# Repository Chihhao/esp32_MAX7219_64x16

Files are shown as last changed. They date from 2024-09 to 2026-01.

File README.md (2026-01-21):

# 💡 ESP32 MAX7219 LED Matrix Display

這是一個基於 ESP32 的 LED 點矩陣顯示專案，整合了 WiFi 網頁設定、RTC 時間顯示、以及條碼掃描器輸入功能，適合用於創客空間或資訊看板。  
本專案提供兩種顯示規格的程式碼：
1.  **64x16 (寬版)**: 使用 16 個 MAX7219 模組 (雙排)。
2.  **64x8 (窄版)**: 使用 8 個 MAX7219 模組 (單排)。

## 📸 專案展示 (Gallery)

### 寬版 (64x16)
Big Demo
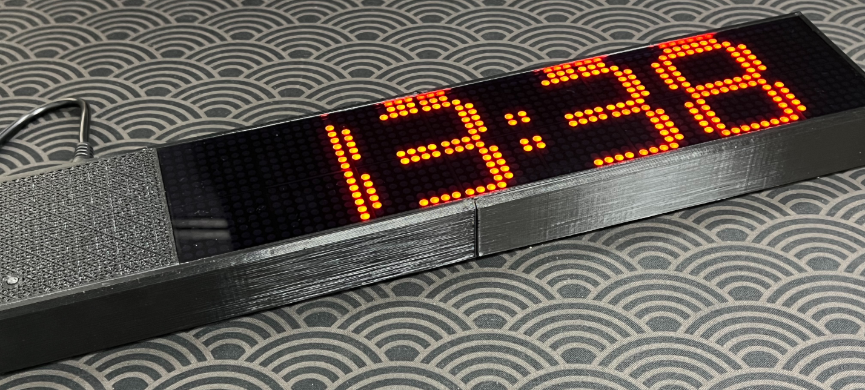
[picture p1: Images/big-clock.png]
Big Clock

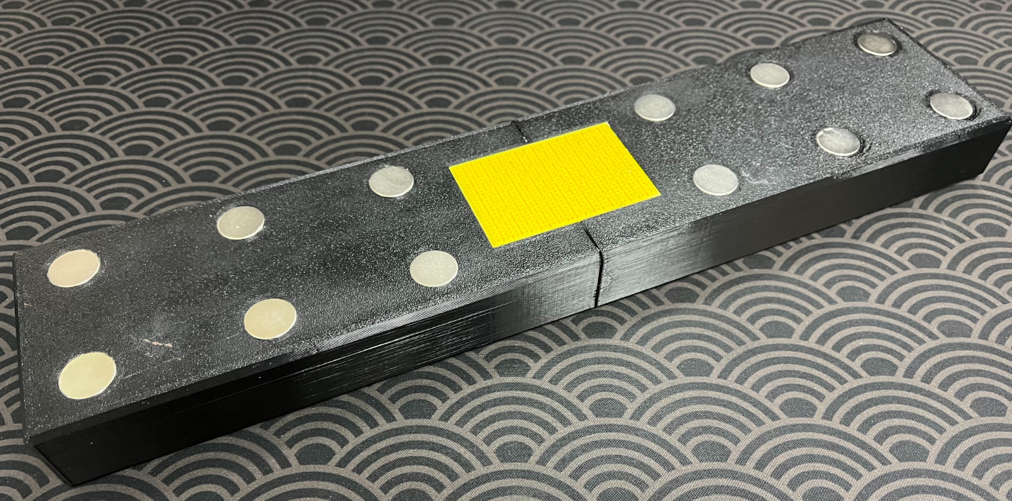
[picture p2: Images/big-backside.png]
Big Backside

Big Inside

### 窄版 (64x8)
Big Demo
Barcode Reader

---

## ✨ 功能特色 (Features)

*   **📶 WiFi AP 設定介面**:
    *   ESP32 啟動後建立獨立熱點 (AP)，方便手機或電腦連線設定。
    *   提供網頁介面修改三組輪播訊息及同步系統時間。
    *   設定內容儲存於 EEPROM，斷電後資料不遺失。
*   **ℹ️ 資訊顯示**:
    *   **輪播訊息**: 支援三組自訂文字訊息 (僅支援英文)，具備滾動與進場動畫效果。
    *   **時間顯示**: 內建 RTC 模組，可顯示大字體時間 (時:分) 與完整日期資訊。
    *   **雙區顯示**:
        *   **64x16**: 分為上下兩區 (Zone Upper / Zone Lower)。
        *   **64x8**: 分為左右兩區 (Zone Left / Zone Right)。
*   **🔫 條碼掃描互動**:
    *   支援 PS2 介面的條碼掃描器。
    *   掃描條碼後，螢幕會暫停輪播，立即顯示掃描到的內容 (停留 30 秒)。
*   **🌱 節能排程**:
    *   內建工作時間判斷，僅在 **08:30 ~ 17:30** 開啟顯示，其餘時間自動關閉以節省電力。

## 📦 版本說明 (Versions)

### 1. 64x16 寬版 (主要版本)
*   **程式碼路徑**: `esp32_MAX7219_64x16/`
*   **硬體配置**: 16 個 MAX7219 模組，排列為 64行 x 16列。
*   **顯示邏輯**: 上下兩行同步顯示或顯示不同資訊。

### 2. 64x8 窄版
*   **程式碼路徑**: `esp32_MAX7219_64x8/`
*   **硬體配置**: 8 個 MAX7219 模組，排列為 64行 x 8列 (單排)。
*   **顯示邏輯**:
    *   **左側 (Zone Left)**: 固定顯示時間 (時:分)。
    *   **右側 (Zone Right)**: 輪播文字訊息。

## 🛠️ 硬體與製作 (Hardware & Build)

### 📝 材料清單 (BOM)
1.  **微控制器**: NodeMCU-32S (ESP32)
2.  **顯示模組**: MAX7219 Dot Matrix Module (FC-16 形式)
    *   64x16 版本需 16 片 (或 4 組 4合1 模組串接)
    *   64x8 版本需 8 片
3.  **RTC 時鐘模組**: DS3231
4.  **輸入裝置**: PS2 介面條碼掃描器 (或 PS2 鍵盤) + PS/2 母座
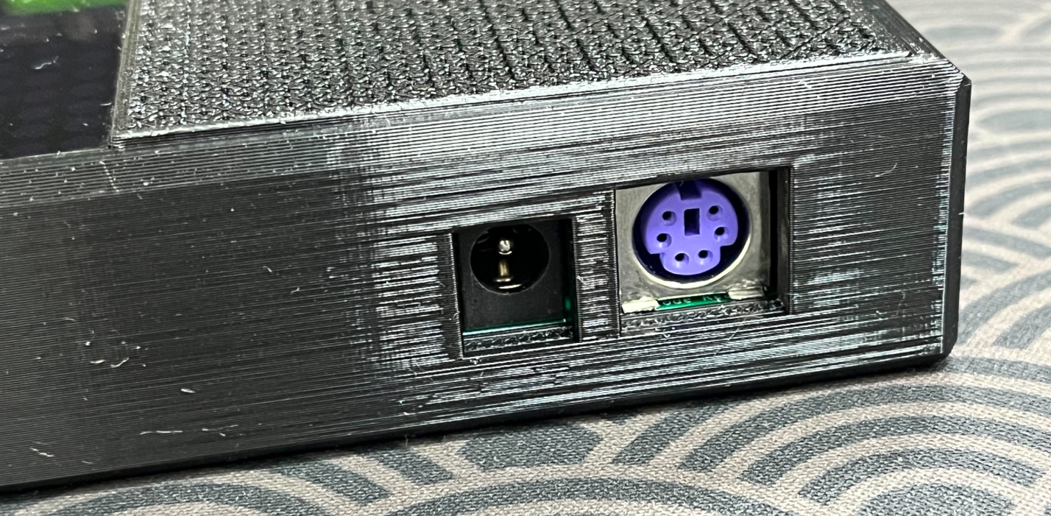
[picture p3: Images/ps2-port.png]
PS2 Port
    
5.  **電源供應**:
    *   **64x16 版本**: 建議使用 **5V 4A** (至少 3A)，以確保全亮時系統穩定。
    *   **64x8 版本**: 建議使用 **5V 2A**。
6.  **其他**:
    *   Reset Button
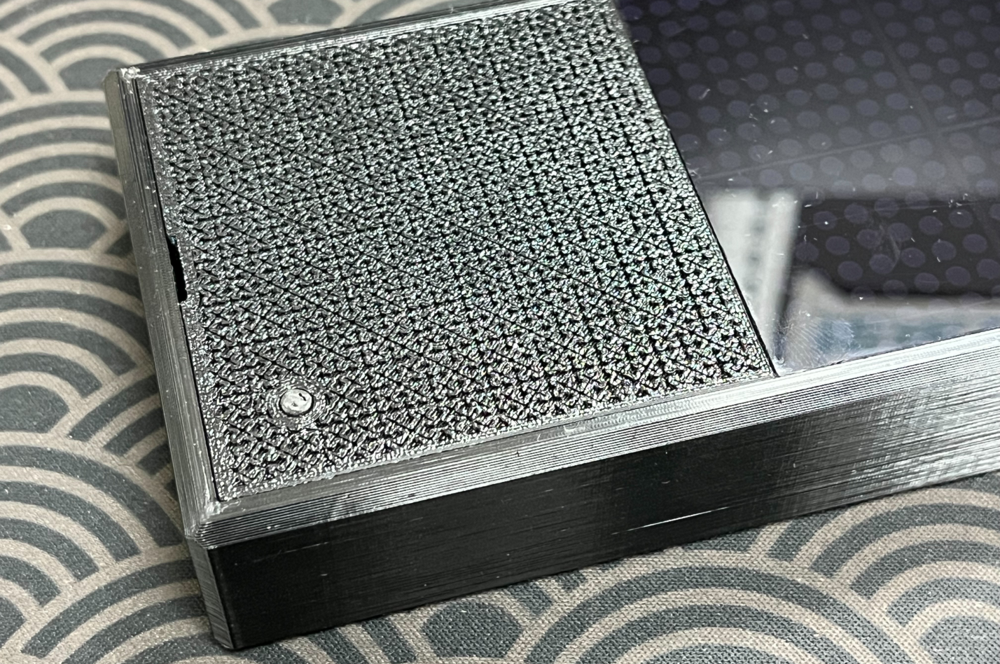
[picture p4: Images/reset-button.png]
Reset Button
        
    *   PCB (可參考下方 Gerber 檔)
    *   3D 列印外殼
    *   強力磁鐵 (直徑 18.2mm / 厚 2mm)
    *   深色透明壓克力 (雷射切割)

### 🔌 接線說明 (Pinout)

| 模組 | 接腳名稱 | ESP32 GPIO | 備註 |
| :--- | :--- | :--- | :--- |
| **MAX7219** | CLK | 18 | SPI Clock |
| | DATA (DIN) | 23 | SPI MOSI |
| | CS | 5 | Chip Select |
| **PS2 Scanner** | Data | 36 | Input Only |
| | Clock | 39 | Input Only |
| **DS3231** | SDA | 21 | I2C SDA (Default) |
| | SCL | 22 | I2C SCL (Default) |

### 原理圖 (Schematic)
Schematic

### PCB 設計
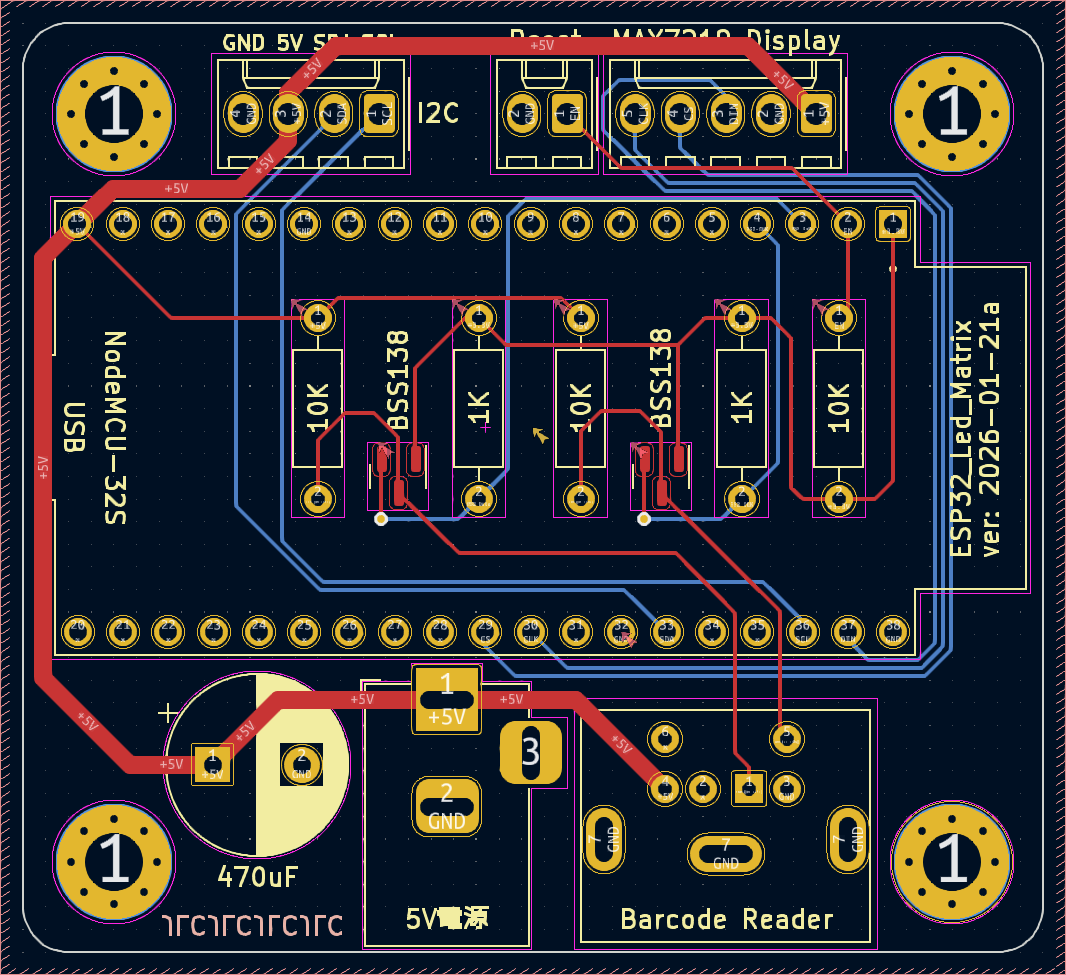
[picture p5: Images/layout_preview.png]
Layout Preview

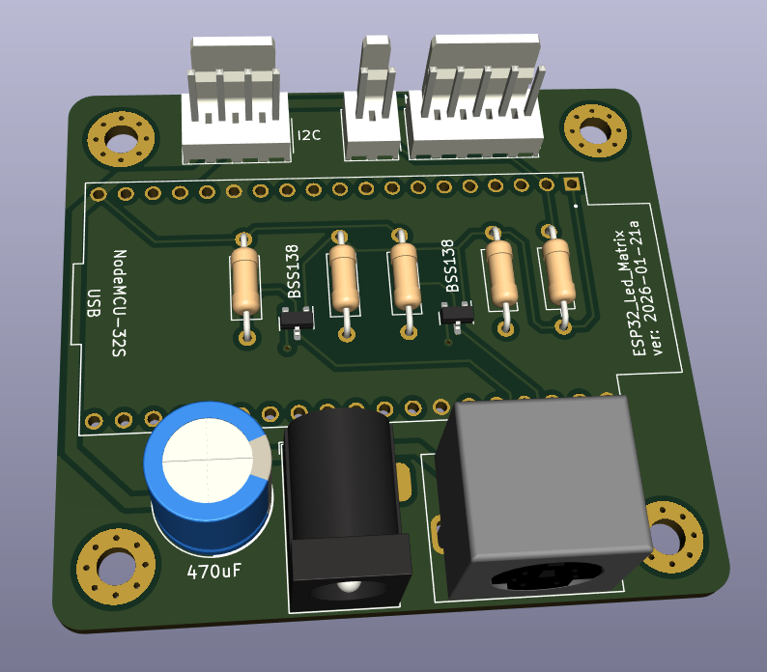
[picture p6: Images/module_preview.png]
Module Preview


### 3D 外殼模型
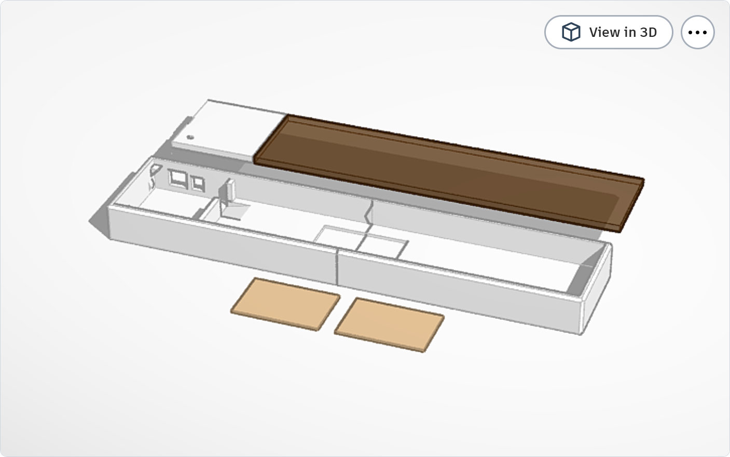
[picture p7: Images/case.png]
Case

* 寬版(64x16) Tinkercad Model: https://www.tinkercad.com/things/0vOz0woKdCv-
* 窄版(64x8) Tinkercad Model: https://www.tinkercad.com/things/j6S2HNCI5wD-

## 軟體設定 (Software Setup)

### 函式庫依賴
請在 Arduino IDE 中安裝以下函式庫：  
*註：版本號為開發時使用的版本，建議使用最新版，若有問題可嘗試回退。*  
1.  Arduino IDE :  1.8.19  
2.  ESP32 Board Library : 3.0.4  
3.  `MD_Parola` by MajicDesigns (v3.7.3)
4.  `MD_MAX72xx` by MajicDesigns (v3.5.1)
5.  `Bonezegei_DS3231` (v1.0.2)
6.  `PS2Keyboard` (v2.4)
7.  `Time` (TimeLib) (v1.6.1)

## 🚀 使用說明 (Usage)

1.  **⚡ 啟動**: 送電後，顯示器會顯示初始訊息或時間。
2.  **🔗 連線設定**:
    *   搜尋 WiFi SSID: `ESP32_LedDisplay` (64x16) 或 `LedDisplay_Nory` (64x8)
    *   密碼: `ESP32_LedDisplay` (64x16) 或 `LedDisplay_Nory` (64x8)
    *   *註：SSID 與密碼定義於程式碼開頭，可自行修改。*
3.  **🌐 網頁控制**:
    *   開啟瀏覽器，輸入網址 `http://192.168.4.1`
    *   **Text Setting**: 輸入 Message 1~3，點擊 "Send Text" 更新顯示。
    *   **Reset Time**: 點擊可將 ESP32 時間同步為目前瀏覽器裝置的時間。
4.  **🔢 條碼輸入**:
    *   直接使用連接的掃描器掃描條碼，螢幕將顯示 "Input: [條碼內容]"。

## ⚠️ 注意事項
*   **工作時間**: 若在 08:30 前或 17:30 後測試，螢幕將保持關閉。可修改程式碼中的 `isWorkTime()` 函式調整時段。
*   **PS2 接腳**: GPIO 36/39 為僅輸入 (Input Only) 接腳，適用於單向傳輸的掃描器。

---

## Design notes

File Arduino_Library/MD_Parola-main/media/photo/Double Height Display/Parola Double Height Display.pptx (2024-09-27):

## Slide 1

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
Rotate 90°

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
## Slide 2

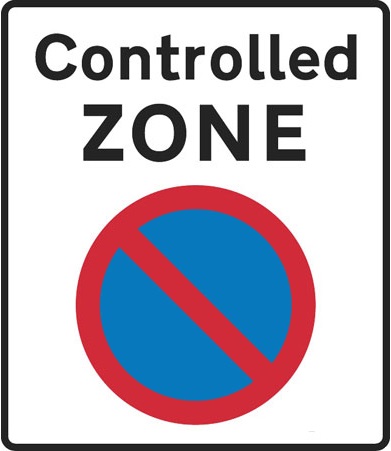
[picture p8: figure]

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
Zone 2

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
Zone 1

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
Zone 0

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
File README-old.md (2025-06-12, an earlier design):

# ESP32 跑馬燈  

## 功能  
1. 跑馬燈，三條訊息輪播 (僅支援英文)  
2. 顯示時間  
3. 顯示條碼機輸入 (最多20碼)  
4. 透過 wifi 設定跑馬燈的訊息與時間  
    (1) 連接 SSID: ESP32_LedDisplay，密碼: 1234567890  
    (2) 瀏覽 http://192.168.4.1  

### 寬版(64*16)
  
  
  
  
  
  

### 窄版(64*8)


## 材料
(1) NodeMCU-32S  
(2) MAX7219 LED點矩陣顯示模組 (64x16)  
(3) DS3231 RTC模組  
(4) Reset Button  
(5) PS/2 母座  
(6) PCB (JLCPCB)  
(7) 3D 列印外殼 ([抗靜電PLA](https://mastech3d.shopstore.tw/item/MPLAE5?srsltid=AfmBOordnhgKTl34iQG4GHte7n62okU-jecyvpEcQZp8lnUj-52Lklmb))  
(8) 強力磁鐵 (直徑 18.2mm / 厚 2mm)  
(9) 深色透明壓克力 (雷射切割)  

## Arduino Library Version  
(1) IDE: Arduino 1.8.19  
(2) Board Library: ESP32 3.0.4  
(3) MD_MAX72XX 3.5.1  
(4) MD_Parola  3.7.3  
(5) Bonezegei_DS3231 1.0.2  
(6) PS2Keyboard 2.4  
(7) Time 1.6.1  

## 原理圖  
  

## PCB
  
  

## 3D Model  
* [寬版(64*16)] Tinkercad Model: https://www.tinkercad.com/things/0vOz0woKdCv-
* [窄版(64*8)] Tinkercad Model: https://www.tinkercad.com/things/j6S2HNCI5wD-


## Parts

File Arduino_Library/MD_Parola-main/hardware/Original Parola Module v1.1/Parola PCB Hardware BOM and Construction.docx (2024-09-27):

# Parola for Arduino Hardware - Bill of Materials and Assembly

## Bill of Materials

Qty | Part | Description
1 | PCB | Printed Circuit Board.
1 | Maxim MAX7219 IC | LED controller.
1 | LD-1088 | 8x8 3mm common anode LED matrix display.
1 | 5 pin 2.54 mm single row angled socket connector | Right angle connector (female) cut from longer length.
1 | 5 pin 2.54 mm single row angled pin connector | Right angle connector (male) cut from longer length.
2 | 8 pin DIP IC socket strip | Socket strip cut from longer length, one for each side of the LED matrix.
1 | 62k Ohm resistor | Resistor sized according to rules for Rset in the MAX7219 datasheet – refer to the datasheet for appropriate values. Something close is sufficient as long as all the resistors are the same, as this controls the LED brightness.
1 | 10µF electrolytic capacitor | Electrolytic capacitor
1 | 0.1µF ceramic capacitor | Ceramic capacitor

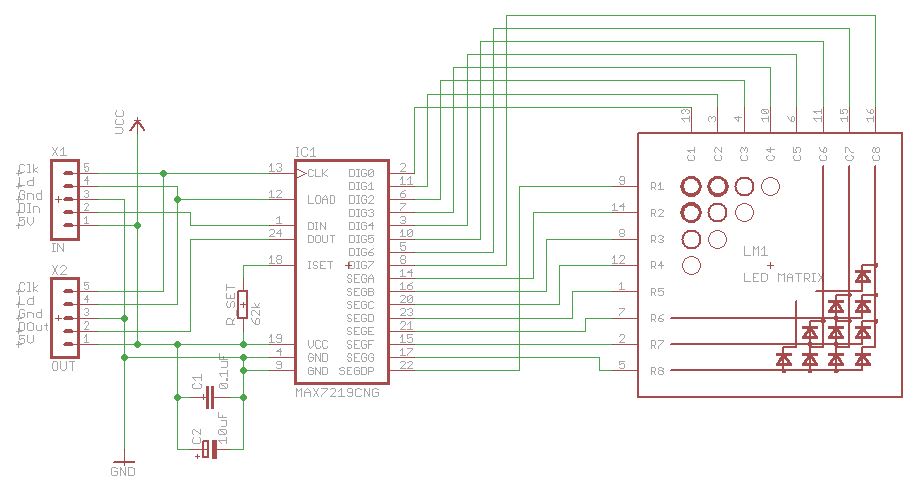
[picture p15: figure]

Figure 1 – Hardware Circuit Schematic

## Component Sources

The PCB can be manufactured at Seeed Studio (http://www.SeeedStudio.com) using the files available on the project web site. The zip file distributed contains all the data required by this service. PCB manufacturing can be found in the Services menu, and the board size is 30x50 mm.

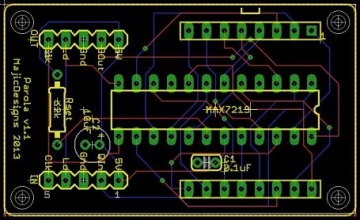
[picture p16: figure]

Figure 2 - PCB Layout

Tayda Electronics (http://www.taydaelectronics.com) is an inexpensive source for all the components

- MAX7219 ICs (Part number A-1018)
- LED Dot Matrix 8x8 Display Red 3mm Common Anode (A-1013)
- 40 Pin 2.54 mm Angle Single Row Pin Header (A-199)
- 40 Pin 2.54 mm Single Row Right Angle Female Pin Header (A-1012)
- 40 Pin DIP SIP IC Sockets Adaptor Solder Type (A-1605)
- 62k Ohm 1/4W 5% Carbon Film Resistor (A-2122)
- 10µF 50V 105C Radial Electrolytic Capacitor 5x11mm (A-4554)
- 0.10µF 50V Multilayer Ceramic Capacitor (A-214)

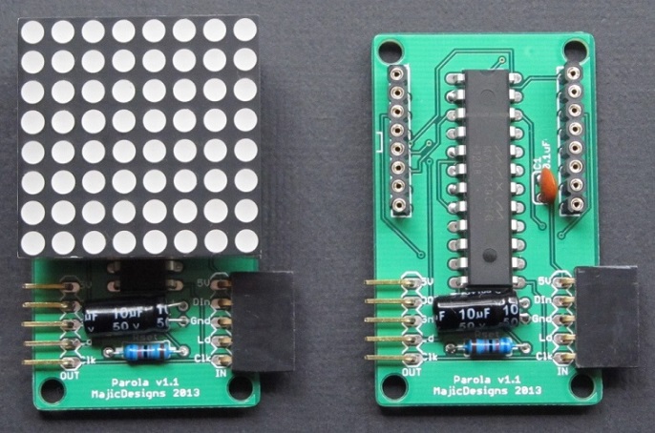
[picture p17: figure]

Figure 3 - Completed hardware

## Assembly Instructions

All items, except for the edge connectors and the LED matrix, are straightforward to assemble. The recommended order of assembly is:

i. Edge connectors
ii. Resistor
iii. Integrated Circuit – insert as per silk screen orientation, without IC socket
iv. Capacitors – note polarity on the 10µF electrolytic capacitor
v. LED matrix, with socket attached

### The Edge Connectors

This process is easiest if two modules are assembled concurrently.

1. Cut 5 pins from the female edge connector. The strip need has to be separated in the middle of the 6th connector. Use sandpaper or a file to neaten up the jagged cut end.
2. Do the same for the male connector. In this case, the separation is between pins.

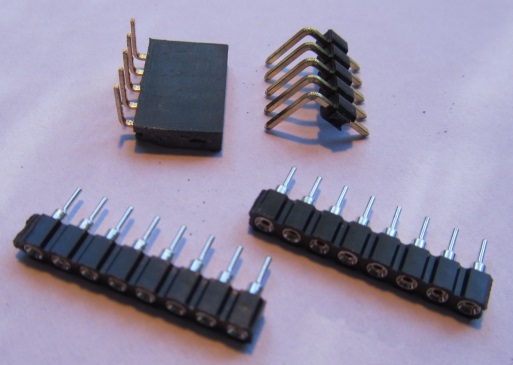
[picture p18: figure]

Figure 4 - Connectors cut to size

3. Remove the angled header pins from their plastic matrix. They should slide out relatively easily. If they don’t, use side cutters to break away the plastic material. You will be left with 5 right angle pins with one leg slightly longer than the other.

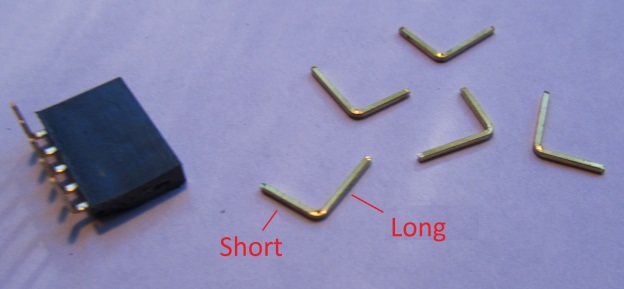
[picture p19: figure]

Figure 5 - Separated pins

4. Insert the shorter end into the socket so that the final subassembly looks like Figure 6 below.

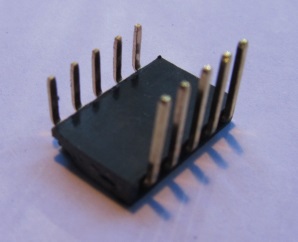
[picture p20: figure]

Figure 6 - Connector subassembly

5. Insert the connector subassembly into 2 inverted PCBs laid alongside each other, supported by the long socket strips. This ensures that the connector assembly remains flat and parallel to the PCB, as the spacers and connectors are the same thickness.

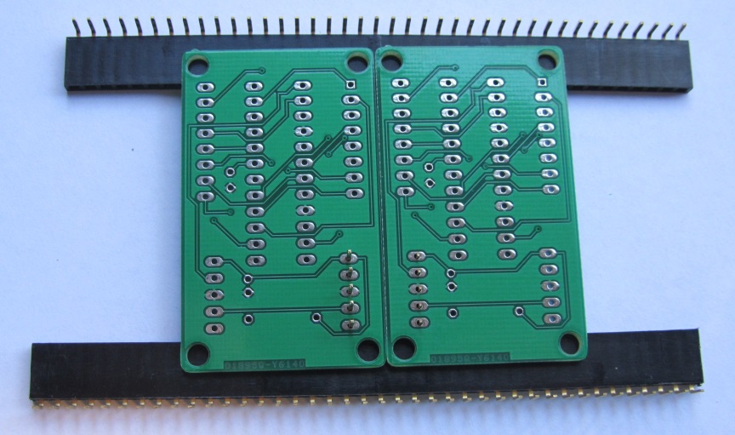
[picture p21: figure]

Figure 7 - PCB supported for connector soldering

6. Double check that the PCBs and the connectors are inserted in the same direction as modules already assembled, and that the PCB is really upside-down (no silk screen text visible).
7. Check that the two PCBS are lying parallel to each other, either touching or with a consistent small (< 1 mm) gap along the common long edge. Ensure this gap remains the same while you solder the edge connector in place.

### The LED Matrix

1. Attached the IC socket strips to the LED matrix pins. This makes it easier to insert the pins into the PCB as they remain straighter and stiffer than the ‘bare’ pins. Ensure they are fully inserted.

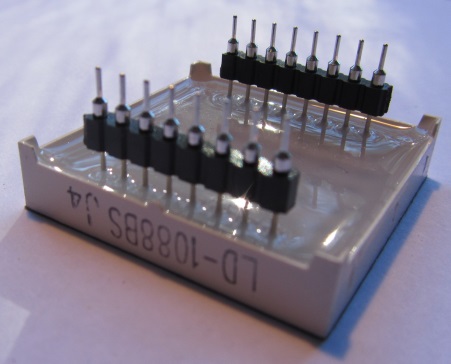
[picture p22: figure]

Figure 8 - LED matrix inserted into socket strip

2. One edge of the LED matrix has a small plastic square tab on the lower edge. This should be aligned with the square mark silkscreened near the edge of the PCB.


Figure 9 - Alignment tab and PCB silkscreen

3. Insert the LED matrix with sockets connected into the PCB.
4. Invert the PCB and press down on the back to ensure that the pins are pushed into the PCB holes as far as they will go. This ensures that the faces of all the matrices will be flush when the modules are connected side by side.
5. While keeping pressure, solder the four corner pins to lock it in place. Check that the matrix is correctly inserted before completely soldering all the remaining LED matrix pins to the PCB.

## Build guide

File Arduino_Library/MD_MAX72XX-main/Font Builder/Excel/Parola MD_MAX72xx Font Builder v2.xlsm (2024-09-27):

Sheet: Instructions
MD_MAX72xx and Parola Font Editor v2.1
Purpose
The purpose of this workbook is to simplify the coding of LED matrix font files for the MD_MAX72xx and MD_Parola libraries. All characters are 8 or 16 pixels high and can be as wide as necessary. This tool allows up to 10 columns.
Principles of Operation
The font definitions are a series of bytes representing columns of data (one column of the LED display) preceded by the number of bytes in that definition. This allows both variable size characters and fixed size characters to be defined in the same way. The ASCII code for the character is inferred from the position in the file (i.e., the 100th character definition is for ASCII value 99, as numbering starts at 0).
5, 62, 107, 79, 107, 62, // 2 - Happy Smiley
In the above example, 5 is the number of bytes in the definition and the remaining bytes are the bitmap for the character. The comment line is auto generated by this tool to include the ASCII value and the optional label entered for this character.
Workflow
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

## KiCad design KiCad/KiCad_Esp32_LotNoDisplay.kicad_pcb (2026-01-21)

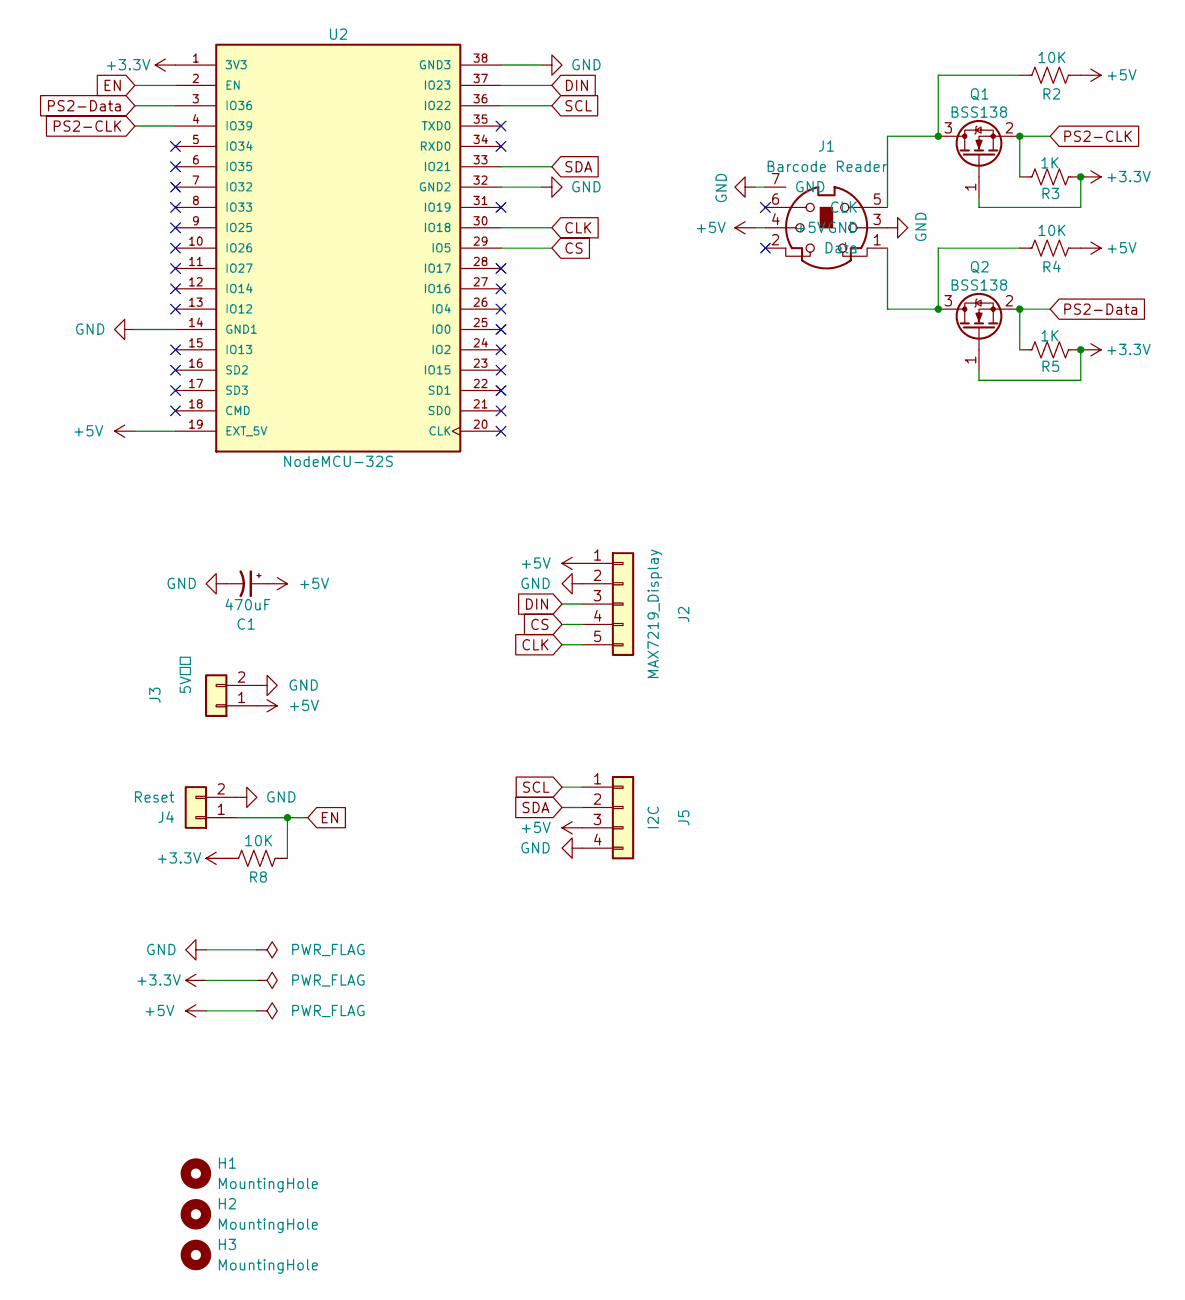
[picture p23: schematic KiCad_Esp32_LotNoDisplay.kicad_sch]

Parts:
C1: 470uF; CP_Radial_D10.0mm_P5.00mm
H1, H2, H3: MountingHole; MountingHole_3.2mm_M3_Pad_Via
J1: Barcode Reader; Connector_Mini-DIN_Female_6Pin_2rows
J2: MAX7219_Display; Molex_KK-254_AE-6410-04A_1x04_P2.54mm_Vertical
J3: 5V電源; TerminalBlock_Phoenix_MKDS-1,5-2-5.08_1x02_P5.08mm_Horizont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
J4: Reset; Molex_KK-254_AE-6410-02A_1x02_P2.54mm_Vertical
J5: I2C; Molex_KK-254_AE-6410-04A_1x04_P2.54mm_Vertical
Q1, Q2: BSS138; SOT-23
R2, R4, R8: 10K; R_0805_2012Metric_Pad1.20x1.40mm_HandSolder
R3, R5: 1K; R_0805_2012Metric_Pad1.20x1.40mm_HandSolder
U2: NodeMCU-32S; MODULE_ESP32-DEVKITC; PARTREV N/A

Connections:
+3.3V: Q1.1 (G), Q2.1 (G), R3.1, R5.1, R8.2, U2.1 (3V3)
+5V: C1.1, J1.4 (+5V), J2.1, J3.1, J5.3, R2.1, R4.1, U2.19 (EXT_5V)
CLK: J2.5, U2.30 (IO18)
CS: J2.4, U2.29 (IO5)
DIN: J2.3, U2.37 (IO23)
EN: J4.1, R8.1, U2.2 (EN)
GND: C1.2, J1.3 (GND), J1.7 (GND), J2.2, J3.2, J4.2, J5.4, U2.14 (GND1), U2.32 (GND2), U2.38 (GND3)
unnamed: J1.1 (Data), Q2.3 (D), R4.2
unnamed: J1.5 (CLK), Q1.3 (D), R2.2
PS2-CLK: Q1.2 (S), R3.2, U2.4 (IO39)
PS2-Data: Q2.2 (S), R5.2, U2.3 (IO36)
SCL: J5.1, U2.36 (IO22)
SDA: J5.2, U2.33 (IO21)

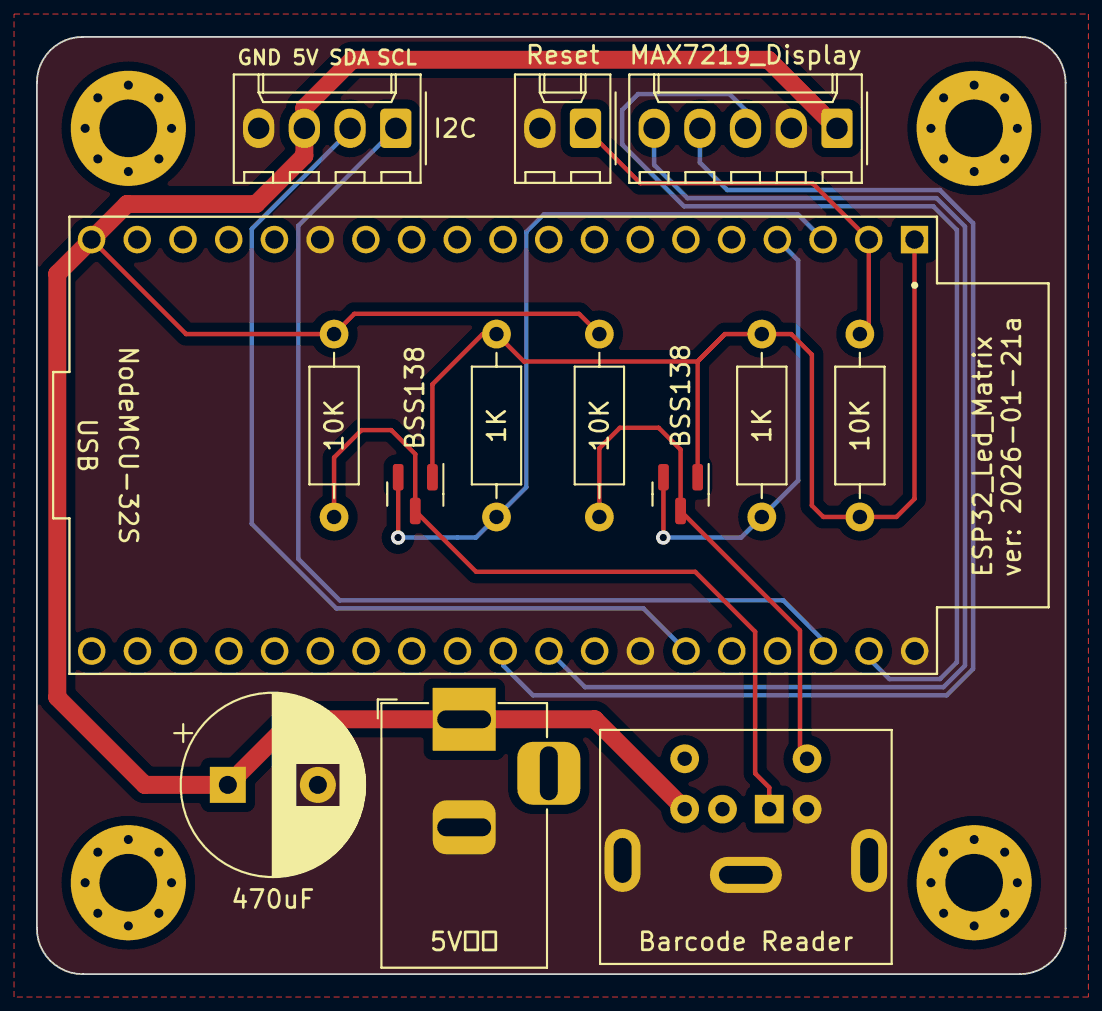
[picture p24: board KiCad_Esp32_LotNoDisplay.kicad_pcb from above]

Board: 2 copper layers, 57.1 x 52.1 mm, 18 parts (0 on the bottom side), 13 nets.

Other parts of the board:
H4: MountingHole; MountingHole_3.2mm_M3_Pad_Via

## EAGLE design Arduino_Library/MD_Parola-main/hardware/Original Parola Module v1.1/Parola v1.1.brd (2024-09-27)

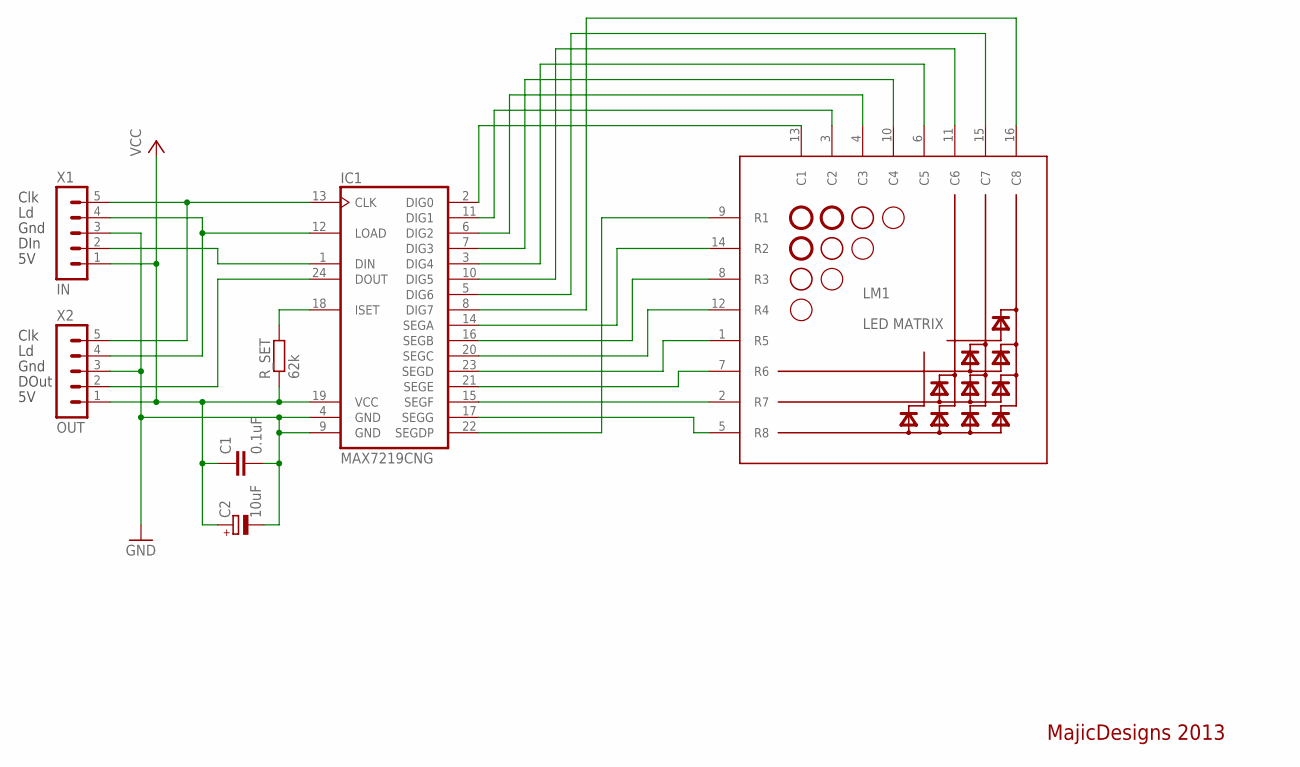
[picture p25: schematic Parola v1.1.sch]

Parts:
C1: 0.1uF; C025-024X044
C2: 10uF; E2-5
IC1: MAX7219CNG; DIL24-3
LM1: LED MATRIX; LED_MATRIX
R_SET: 62k; 0207/10
X1: IN; MAR05-1
X2: OUT; MAR05-1

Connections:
GND: C1.2, C2.-, IC1.4 (GND), IC1.9 (GND), X1.3, X2.3
unnamed: IC1.17 (SEGG), LM1.5 (R8)
unnamed: IC1.15 (SEGF), LM1.2 (R7)
unnamed: IC1.21 (SEGE), LM1.7 (R6)
unnamed: IC1.23 (SEGD), LM1.1 (R5)
unnamed: IC1.20 (SEGC), LM1.12 (R4)
unnamed: IC1.16 (SEGB), LM1.8 (R3)
unnamed: IC1.14 (SEGA), LM1.14 (R2)
unnamed: IC1.22 (SEGDP), LM1.9 (R1)
unnamed: IC1.8 (DIG7), LM1.16 (C8)
unnamed: IC1.5 (DIG6), LM1.15 (C7)
unnamed: IC1.10 (DIG5), LM1.11 (C6)
unnamed: IC1.3 (DIG4), LM1.6 (C5)
unnamed: IC1.7 (DIG3), LM1.10 (C4)
unnamed: IC1.6 (DIG2), LM1.4 (C3)
unnamed: IC1.11 (DIG1), LM1.3 (C2)
unnamed: IC1.2 (DIG0), LM1.13 (C1)
unnamed: IC1.13 (CLK), X1.5, X2.5
unnamed: IC1.12 (LOAD), X1.4, X2.4
unnamed: IC1.1 (DIN), X1.2
unnamed: IC1.24 (DOUT), X2.2
unnamed: IC1.18 (ISET), R_SET.2
VCC: C1.1, C2.+, IC1.19 (VCC), R_SET.1, X1.1, X2.1

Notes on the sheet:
Clk
Gnd
DIn
DOut
MajicDesigns 2013

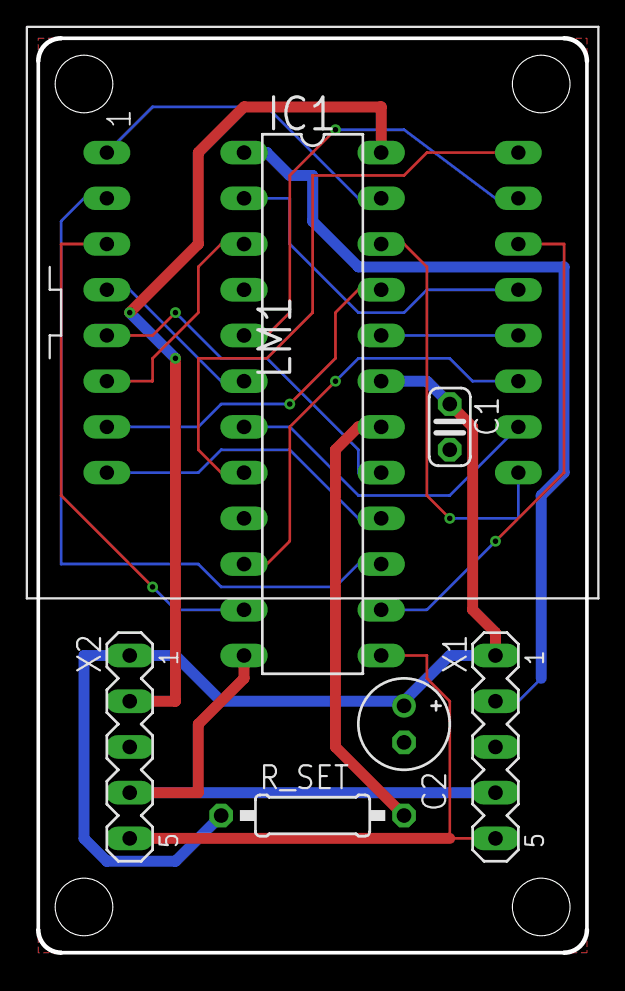
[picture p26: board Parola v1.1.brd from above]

Board: 2 copper layers, 30.5 x 50.8 mm, 7 parts (0 on the bottom side), 23 nets.

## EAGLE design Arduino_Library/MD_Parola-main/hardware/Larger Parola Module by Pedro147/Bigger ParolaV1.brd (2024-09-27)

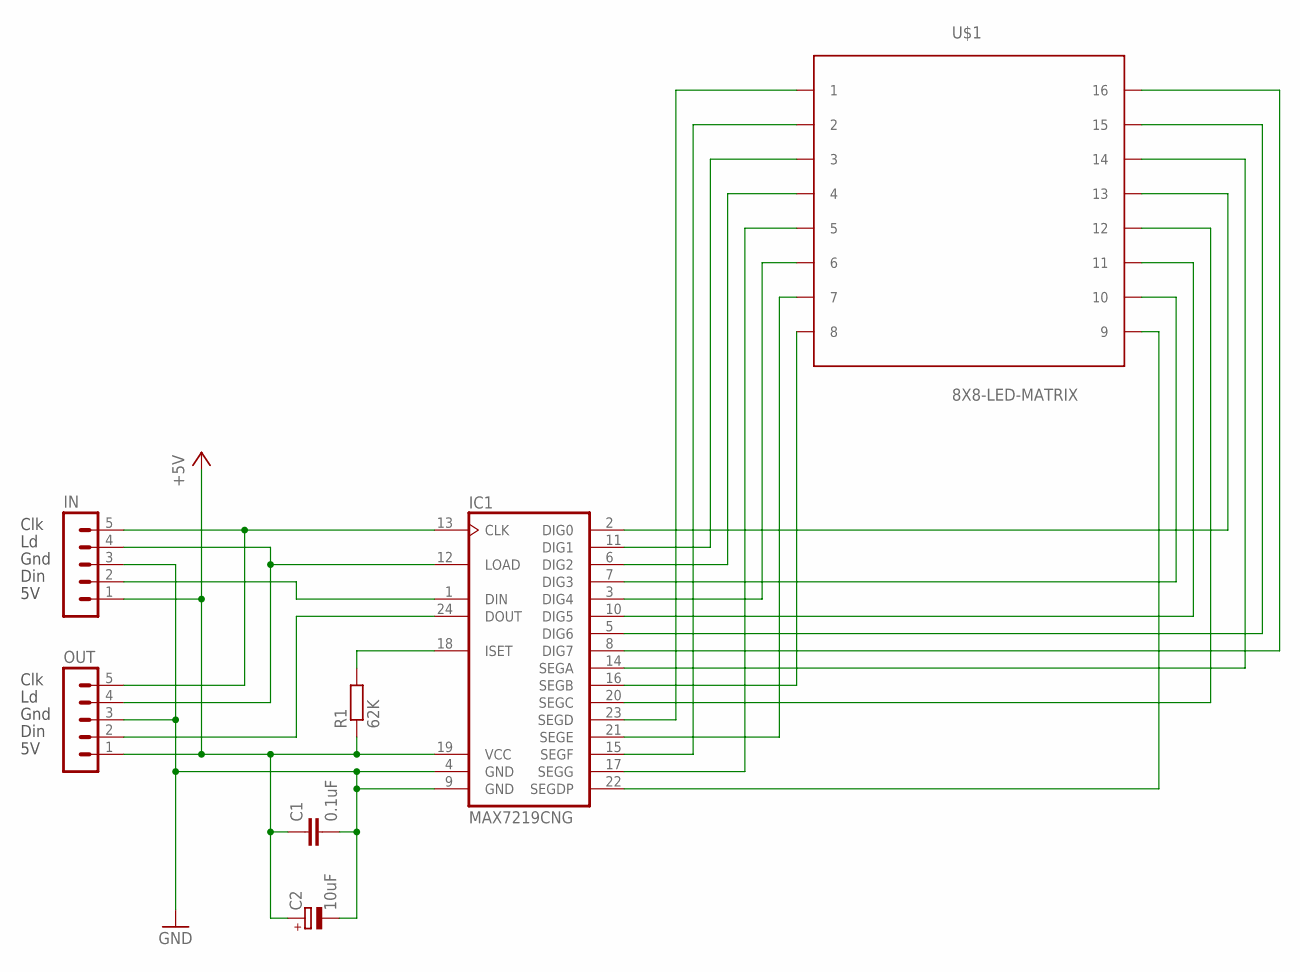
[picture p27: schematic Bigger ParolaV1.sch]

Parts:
C1: 0.1uF; C025-024X044
C2: 10uF; E2-5
IC1: MAX7219CNG; DIL24-3
IN: MAR05-1
OUT: MAR05-1
R1: 62K; 0207/10
U$1: 8X8-LED-MATRIX

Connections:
+5V: C1.1, C2.+, IC1.19 (VCC), IN.1, OUT.1, R1.1
GND: C1.2, C2.-, IC1.4 (GND), IC1.9 (GND), IN.3, OUT.3
unnamed: IC1.18 (ISET), R1.2
unnamed: IC1.24 (DOUT), OUT.2
unnamed: IC1.12 (LOAD), IN.4, OUT.4
unnamed: IC1.13 (CLK), IN.5, OUT.5
unnamed: IC1.1 (DIN), IN.2
unnamed: IC1.2 (DIG0), U$1.P$13 (13)
unnamed: IC1.11 (DIG1), U$1.P$3 (3)
unnamed: IC1.6 (DIG2), U$1.P$4 (4)
unnamed: IC1.7 (DIG3), U$1.P$10 (10)
unnamed: IC1.3 (DIG4), U$1.P$6 (6)
unnamed: IC1.10 (DIG5), U$1.P$11 (11)
unnamed: IC1.5 (DIG6), U$1.P$15 (15)
unnamed: IC1.8 (DIG7), U$1.P$16 (16)
unnamed: IC1.14 (SEGA), U$1.P$14 (14)
unnamed: IC1.16 (SEGB), U$1.P$8 (8)
unnamed: IC1.20 (SEGC), U$1.P$12 (12)
unnamed: IC1.23 (SEGD), U$1.P$1 (1)
unnamed: IC1.21 (SEGE), U$1.P$7 (7)
unnamed: IC1.15 (SEGF), U$1.P$2 (2)
unnamed: IC1.17 (SEGG), U$1.P$5 (5)
unnamed: IC1.22 (SEGDP), U$1.P$9 (9)

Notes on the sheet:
Clk
Gnd
Din

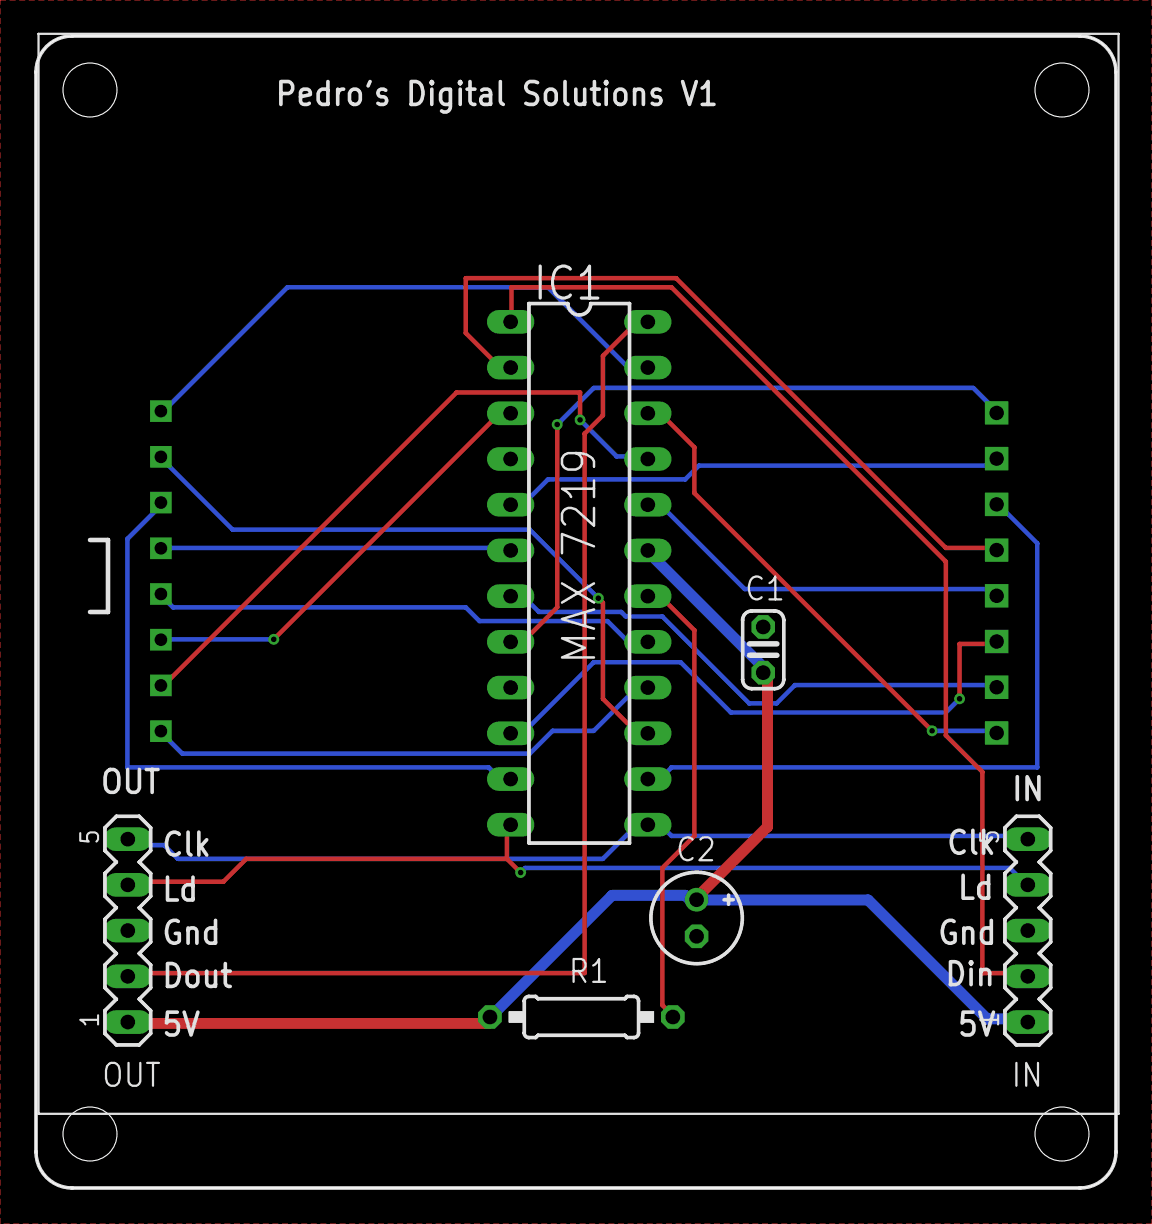
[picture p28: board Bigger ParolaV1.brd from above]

Board: 2 copper layers, 60.0 x 64.0 mm, 7 parts (0 on the bottom side), 23 nets.

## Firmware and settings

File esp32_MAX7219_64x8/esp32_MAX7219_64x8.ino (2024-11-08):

#include <WiFi.h>
#include <WiFiServer.h>
#include <EEPROM.h>
#include <MD_Parola.h>
#include <MD_MAX72xx.h>
#include <SPI.h>
#include <Bonezegei_DS3231.h>
#include <PS2Keyboard.h>
#include <TimeLib.h>
#include "Font_Data.h"

#define PRINT(s, v) { Serial.print(F(s)); Serial.println(v); }
#define PRINTS(s)   { Serial.println(F(s)); }

const char* ssid     = "LedDisplay_Nory";
const char* password = "LedDisplay_Nory";
WiFiServer server(80);
Bonezegei_DS3231 rtc(0x68);
PS2Keyboard keyboard;

#define HARDWARE_TYPE MD_MAX72XX::FC16_HW
// #define MAX_ZONES 2
// #define ZONE_SIZE 8
// #define MAX_DEVICES (MAX_ZONES * ZONE_SIZE)
#define MAX_DEVICES 8

// #define ZONE_UPPER  1
// #define ZONE_LOWER  0
#define ZONE_LEFT 0 
#define ZONE_RIGHT 1 

#define CLK_PIN   18  // or SCK
#define DATA_PIN  23  // or MOSI
#define CS_PIN    5   // or SS
#define PS2_DATA  36  // INPUT
#define PS2_CLOCK 39  // INPUT

#define BARCODE_DISPLAY_TIME 30
#define TIMEMODE_DISPLAY_TIME 30

MD_Parola P = MD_Parola(HARDWARE_TYPE, CS_PIN, MAX_DEVICES);

#define ARRAY_SIZE(a) (sizeof(a)/sizeof(a[0]))

int scroll_speed=100;
const uint8_t MESG_SIZE = 100;
char newMessage[MESG_SIZE];
bool newMessageAvailable = false;
bool PAUSE_DISPLAY = false;
bool TIME_MODE = false;
unsigned long ulPauseTime=0;
unsigned long ulLastShowClockTime=0;
char dynamicWebPage[3000];

const char WebResponse[] = "HTTP/1.1 200 OK\nContent-Type:text/html\n\n";
const char WebPage[] =
"<!DOCTYPE html>" \
"<html>" \
"<head>" \
"<META HTTP-EQUIV=\"EXPIRES\" CONTENT=\"Mon, 22 Jul 2002 11:12:01 GMT\">" \
"<META name=\"viewport\" content=\"width=device-width, initial-scale=1\">" \
"<title>LED Matrix Text Setting</title>" \

"<script>" \
"strLine = \"\";" \

"function SendText() {" \
"  nocache = \"/&nocache=\" + Math.random() * 1000000;" \
"  var request = new XMLHttpRequest();" \
"  strLine = \"&MSG1=\" + document.getElementById(\"txt_form\").Message1.value + \"/&MSG2=\" + document.getElementById(\"txt_form\").Message2.value + \"/&MSG3=\" + document.getElementById(\"txt_form\").Message3.value+ \"/&TIME=\" + Date.now();" \
"  request.open(\"GET\", strLine + nocache, false);" \
"  request.send(null);" \
"}" \

"function ResetText() {" \
"  nocache = \"/&nocache=\" + Math.random() * 1000000;" \
"  var request = new XMLHttpRequest();" \
"  strLine = \"&MSG1=MK350/&MSG2=NoryLee/&MSG3=Happy everyday!/&TIME=\" + Date.now();" \
"  request.open(\"GET\", strLine + nocache, false);" \
"  request.send(null);" \
"}" \

"function ResetTime() {" \
"  nocache = \"/&nocache=\" + Math.random() * 1000000;" \
"  var request = new XMLHttpRequest();" \
"  strLine = \"&TIME=\" + Date.now();" \
"  request.open(\"GET\", strLine + nocache, false);" \
"  request.send(null);" \
"}" \

"</script>" \
"</head>" \

"<body>" \
"<p><b>LED Matrix Text Setting</b></p>" \

"<form id=\"txt_form\" name=\"frmText\">" \
"<label>1: <input type=\"text\" name=\"Message1\" maxlength=\"100\" value=\"__MSG1__\" ></label><br><br>" \
"<label>2: <input type=\"text\" name=\"Message2\" maxlength=\"100\" value=\"__MSG2__\" ></label><br><br>" \
"<label>3: <input type=\"text\" name=\"Message3\" maxlength=\"100\" value=\"__MSG3__\" ></label><br><br>" \
"</form>" \
"<br>" \
"<input type=\"button\" value=\"Send Text\" onclick=\"SendText()\">" \
"<input type=\"button\" value=\"Reset Text\" onclick=\"ResetText()\">" \
"<input type=\"button\" value=\"Reset Time\" onclick=\"ResetTime()\">" \
"</body>" \
"</html>";

char msg[3][200];
uint8_t msgIdx = 0;
char timeStamp[50];

char szTimeL[12];
char szTimeH[12];

void initializeFirstTime(){
  strcpy(msg[0], "MK330");
  strcpy(msg[1], "B/E Maker Space");
  strcpy(msg[2], "Chihhao Lai");
  saveBasicData();
}

void saveBasicData(){
  EEPROM_writeAnything(0, msg);
  delay(2);
}

//https://forum.arduino.cc/index.php?topic=41497.0
template <class T> int EEPROM_writeAnything(int ee, const T& value){
   const byte* p = (const byte*)(const void*)&value;
   int i;
   for (i = 0; i < sizeof(value); i++){
       EEPROM.write(ee++, *p++);
       vTaskDelay(1); //避免觸發看門狗
   }
   EEPROM.commit(); 
   return i;
}

//https://forum.arduino.cc/index.php?topic=41497.0
template <class T> int EEPROM_readAnything(int ee, T& value){
   byte* p = (byte*)(void*)&value;
   int i;
   for (i = 0; i < sizeof(value); i++){
       *p++ = EEPROM.read(ee++);
   }
   return i;
}

void readBasicData(){
  EEPROM_readAnything(0, msg);
  PRINT("msg[0]", msg[0]);
  PRINT("msg[1]", msg[1]);
  PRINT("msg[2]", msg[2]);
}

void setup(void){    
    Serial.begin(115200);
    PRINTS("[start]");

    //從EEPROM載入設定
    PRINTS("enable EEPROM");
    EEPROM.begin(4096); 
    //initializeFirstTime();
    readBasicData();

    PRINTS("enable RTC");
    rtc.begin();
    rtc.setFormat(24);

    PRINTS("enable KEYBOARD");
    keyboard.begin(PS2_DATA, PS2_CLOCK);
    keyboard.clear();

    PRINTS("Setting AP (Access Point)…");
    WiFi.softAP(ssid, password);
    IPAddress IP = WiFi.softAPIP();
    PRINT("AP IP address:", IP);
    server.begin();
      
    P.begin(2);
    P.setZone(ZONE_LEFT, 5, 7);
    P.setZone(ZONE_RIGHT, 0, 4);
//    P.setZone(ZONE_LEFT, 0, 2);
//    P.setZone(ZONE_RIGHT, 3, 7);
//    P.setZoneEffect(ZONE_LEFT, true, PA_FLIP_UD);
//    P.setZoneEffect(ZONE_LEFT, true, PA_FLIP_LR);
//    P.setZoneEffect(ZONE_RIGHT, true, PA_FLIP_UD);
//    P.setZoneEffect(ZONE_RIGHT, true, PA_FLIP_LR);
    P.setCharSpacing(1);
    P.setFont(ZONE_LEFT, numeric7Seg);
    P.setFont(ZONE_RIGHT, NULL);
    //P.setInvert(false);
    P.displayZoneText(ZONE_LEFT, szTimeL, PA_CENTER, 0, 0, PA_PRINT, PA_NO_EFFECT);
    
}

void loop(void){
    handleWiFi();
    String lotString = checkBarCode();
    if(lotString.length() > 0){      
        char message[50];
        lotString.toCharArray(message, lotString.length()+1);
        message[10] = '\0';
        PRINT("ScanInput: ", message);
        
        PAUSE_DISPLAY = true;
        ulPauseTime = millis();
        
        P.displayClear();
        P.setZone(ZONE_LEFT, 0, 7);
        //P.setZoneEffect(ZONE_LEFT, true, PA_FLIP_UD);
        //P.setZoneEffect(ZONE_LEFT, true, PA_FLIP_LR);
        P.setCharSpacing(1);
        P.setFont(ZONE_LEFT, NULL);
        P.displayZoneText(ZONE_LEFT, message, PA_CENTER, 0, 0, PA_NO_EFFECT, PA_NO_EFFECT);
                
        P.displayReset(ZONE_LEFT);
        P.displayAnimate();
    }

    if(PAUSE_DISPLAY){
        if(millis() - ulPauseTime >= BARCODE_DISPLAY_TIME * 1000){  
            PAUSE_DISPLAY = false;
        }
    }
    if(!PAUSE_DISPLAY){ 
        
        if(!isWorkTime()){ // Work Time: 0830-1730
            P.displayClear();
            delay(10);
            return;
        }

        P.setZone(ZONE_LEFT, 5, 7);
        P.setZone(ZONE_RIGHT, 0, 4);
//        P.setZone(ZONE_LEFT, 0, 2);
//        P.setZone(ZONE_RIGHT, 3, 7);
//        P.setZoneEffect(ZONE_LEFT, true, PA_FLIP_UD);
//        P.setZoneEffect(ZONE_LEFT, true, PA_FLIP_LR);
//        P.setZoneEffect(ZONE_RIGHT, true, PA_FLIP_UD);
//        P.setZoneEffect(ZONE_RIGHT, true, PA_FLIP_LR);
        P.setCharSpacing(1);
        P.setFont(ZONE_LEFT, numeric7Seg);
        P.setFont(ZONE_RIGHT, NULL);
        
        P.displayAnimate();
        
        P.displayZoneText(ZONE_LEFT, szTimeL, PA_CENTER, 0, 0, PA_PRINT, PA_NO_EFFECT);
        if (millis() - ulLastShowClockTime >= 1000) {
            ulLastShowClockTime = millis();
            getTime1();       
            P.displayReset(ZONE_LEFT);
        }
                
        if (P.getZoneStatus(ZONE_RIGHT)){
            switch (msgIdx){
            case 0:                
                scroll_speed = 80;
                P.displayZoneText(ZONE_RIGHT, msg[msgIdx], PA_CENTER, scroll_speed, 5000, PA_OPENING, PA_CLOSING);
                break;
            case 1:  
                scroll_speed = 80;
                // P.displayZoneText(ZONE_RIGHT, msg[msgIdx], PA_LEFT, scroll_speed, 0, PA_SCROLL_RIGHT, PA_SCROLL_RIGHT);
                P.displayZoneText(ZONE_RIGHT, msg[msgIdx], PA_CENTER, scroll_speed, 5000, PA_SCROLL_LEFT, PA_SCROLL_LEFT);
                break;
            case 2:    
                scroll_speed = 80;
                // P.displayZoneText(ZONE_RIGHT, msg[msgIdx], PA_LEFT, scroll_speed, 0, PA_SCROLL_RIGHT, PA_SCROLL_RIGHT);
                P.displayZoneText(ZONE_RIGHT, msg[msgIdx], PA_CENTER, scroll_speed, 0, PA_SCROLL_LEFT, PA_SCROLL_LEFT);
                
                break; 
            }

            if(msgIdx++ >= 2) { msgIdx = 0; }    
            
            // P.displayClear();
            // P.synchZoneStart();
            P.displayReset(ZONE_RIGHT);
        }  
        
        
          
    
    }

    
    // delay(1);  
}

bool isWorkTime(){
  // Work Time: 0830-1730
  rtc.getTime();
  int _h = rtc.getHour();
  int _m = rtc.getMinute();
  if (_h>=18) { return false; } 
  if (_h==17 && _m>=31) { return false; }  
  if (_h<=7) { return false; }
  if (_h==8  && _m<=29) { return false; }
  return true;
}

WiFiClient client;
enum { S_IDLE, S_WAIT_CONN, S_READ, S_EXTRACT, S_RESPONSE, S_DISCONN } state = S_IDLE;
char szBuf[1024];
uint16_t idxBuf = 0;  
uint32_t timeStart;
void handleWiFi(void){  
  bool needSave = false;
  switch (state){
  case S_IDLE:   // initialize
      PRINTS("S_IDLE");
      idxBuf = 0;
      state = S_WAIT_CONN;
      break;

  case S_WAIT_CONN:   // waiting for connection
      client = server.available();   // listen for incoming clients
      //client = server.accept();
      if (!client) break;
      if (!client.connected()) break;

      char szTxt[20];
      sprintf(szTxt, "%d:%d:%d:%d", client.remoteIP()[0], client.remoteIP()[1], client.remoteIP()[2], client.remoteIP()[3]);
      PRINT("New client @ ", szTxt);

      timeStart = millis();
      state = S_READ;
      break;

  case S_READ: // get the first line of data
      PRINTS("S_READ");
      while (client.available()){
          char c = client.read();
          if ((c == '\r') || (c == '\n')){
              szBuf[idxBuf] = '\0';
              //client.flush();
              PRINT("Recv: ", szBuf);
              state = S_EXTRACT;
              break;
          }
          else{
              szBuf[idxBuf++] = (char)c;
          }
      }
      if (millis() - timeStart > 1000){
          PRINTS("Wait timeout");
          state = S_DISCONN;
      }
      break;

  case S_EXTRACT: // extract data
      PRINTS("S_EXTRACT");
      needSave = false;
      if(getText(szBuf, newMessage, MESG_SIZE, "/&MSG1=")){          
          if(strlen(newMessage)>0){ strcpy(msg[0], newMessage); needSave = true;}
      }
      if(getText(szBuf, newMessage, MESG_SIZE, "/&MSG2=")){
          if(strlen(newMessage)>0){ strcpy(msg[1], newMessage); needSave = true;}
      }
      if(getText(szBuf, newMessage, MESG_SIZE, "/&MSG3=")){
          if(strlen(newMessage)>0){ strcpy(msg[2], newMessage); needSave = true;}
      }  
      if(getText(szBuf, timeStamp, 50, "/&TIME=")){
          PRINT("timeStamp: ", timeStamp);    
          setRtcTime(timeStamp);      
      }  

      if(needSave) { saveBasicData(); }
            
      readBasicData();

      
      state = S_RESPONSE;
      break;

  case S_RESPONSE: // send the response to the client
      PRINTS("S_RESPONSE");
      // Return the response to the client (web page)
      client.print(WebResponse);
      updateWebPage();
      client.print(dynamicWebPage);
      client.println();
      state = S_DISCONN;
      break;

  case S_DISCONN: // disconnect client
      PRINTS("S_DISCONN");
      client.flush();
      client.stop();
      state = S_IDLE;
      break;

  default:  state = S_IDLE;
  }
}

void setRtcTime(char *timeStr){
  timeStr[10] = '\0'; 
  unsigned long t = strtoul(timeStr, NULL, 10) + 28800;  //+8 hrs
  char _time[10], _date[10];
  sprintf(_date, "%d/%d/%d", month(t), day(t), year(t)-2000);  
  sprintf(_time, "%2d:%2d:%2d", hour(t), minute(t), second(t));
  rtc.setDate(_date);  //Set Date    Month/Date/Year
  rtc.setTime(_time);  //Set Time    Hour:Minute:Seconds  
  PRINT("_date: ", _date);
  PRINT("_time: ", _time);  
}

void updateWebPage(){  
  strcpy(dynamicWebPage, WebPage);
  strreplace(dynamicWebPage, "__MSG1__", msg[0]);
  strreplace(dynamicWebPage, "__MSG2__", msg[1]);
  strreplace(dynamicWebPage, "__MSG3__", msg[2]);  
}

char *strreplace(char *s, const char *s1, const char *s2) {
  // https://stackoverflow.com/questions/56043612/how-to-replace-a-part-of-a-string-with-another-substring
    char *p = strstr(s, s1);
    if (p != NULL) {
        size_t len1 = strlen(s1);
        size_t len2 = strlen(s2);
        if (len1 != len2)
            memmove(p + len2, p + len1, strlen(p + len1) + 1);
        memcpy(p, s2, len2);
    }
    return s;
}

boolean getText(char *szMesg, char *psz, uint8_t len, char *msgName){
  boolean isValid = false;  // text received flag
  char *pStart, *pEnd;      // pointer to start and end of text

  // get pointer to the beginning of the text
  //pStart = strstr(szMesg, "/&MSG=");
  pStart = strstr(szMesg, msgName);

  if (pStart != NULL)
  {
    pStart += strlen(msgName);  // skip to start of data
    pEnd = strstr(pStart, "/&");

    if (pEnd != NULL)
    {
      while (pStart != pEnd)
      {
        if ((*pStart == '%') && isxdigit(*(pStart+1)))
        {
          // replace %xx hex code with the ASCII character
          char c = 0;
          pStart++;
          c += (htoi(*pStart++) << 4);
          c += htoi(*pStart++);
          *psz++ = c;
        }
        else
          *psz++ = *pStart++;
      }

      *psz = '\0'; // terminate the string
      isValid = true;
    }
  }

  return(isValid);
}

uint8_t htoi(char c){
  c = toupper(c);
  if ((c >= '0') && (c <= '9')) return(c - '0');
  if ((c >= 'A') && (c <= 'F')) return(c - 'A' + 0xa);
  return(0);
}

String checkBarCode() {

  String barcodeString = "";   

  if (!keyboard.available()) { return ""; } //若無條碼輸入
  unsigned long timeStampKeyboard = 0;

  while (true) { //讀取條碼
    if (keyboard.available()) {    
      timeStampKeyboard = millis();  
      int c = keyboard.read();          
      if (c == 10 || c == 13) {continue;}  // 忽略換行
      if (!isGraph(c)) {continue;}  // 忽略印不出來的字元      
      if (c >= 97 && c <= 122) {c -= 32;} //轉大寫
      //Serial.print(c);

      barcodeString += String((char)c); 
    } 

    if(barcodeString.length() > 0){
      if(millis() - timeStampKeyboard >= 50) {                     
        break;                    
      }              
    }    
  }  
 
  if (barcodeString.length() == 0) {
      return ""; //若無條碼輸入
  }
  else{  
      //PRINT("Barcode Scan Input: ", barcodeString);
      return barcodeString;
  }
}

unsigned long ulLastGetTime=0;
bool flasher = true;
void getTime1(){  
  if (rtc.getTime()) {
    if(millis() - ulLastGetTime >= 1000){  
        ulLastGetTime = millis();  
        flasher = !flasher;
    }
    sprintf(szTimeL, "%02d%c%02d", rtc.getHour(), (flasher?':':' '), rtc.getMinute());
    createHString(szTimeH, szTimeL); 
    //PRINT("szTimeH: ", szTimeH);
    //PRINT("szTimeL: ", szTimeL);    
  }  
}
void createHString(char *pH, char *pL){
  for (; *pL != '\0'; pL++){
    *pH++ = *pL | 0x80;   // offset character
  }
  *pH = '\0'; // terminate the string
}
void getTime2(){  
  if (rtc.getTime()) {
    //Serial.printf("Time %02d:%02d:%02d ", rtc.getHour(), rtc.getMinute(), rtc.getSeconds());
    //Serial.printf("Date %02d-%02d-%d \n", rtc.getMonth(), rtc.getDate(), rtc.getYear());
    if(millis() - ulLastGetTime >= 1000){  
        ulLastGetTime = millis();  
        flasher = !flasher;
    }
    sprintf(szTimeH, "20%02d/%02d/%02d (%d)", rtc.getYear(), rtc.getMonth(), rtc.getDate()/*, rtc.getDay()*/);
    sprintf(szTimeL, "%02d%c%02d%c%02d", rtc.getHour(), (flasher?':':' '), rtc.getMinute(), (flasher?':':' '), rtc.getSeconds());
    
    PRINT("szTimeH: ", szTimeH);
    PRINT("szTimeL: ", szTimeL);    
  }  
}

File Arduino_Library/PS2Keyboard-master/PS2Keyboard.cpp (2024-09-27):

/*
  PS2Keyboard.cpp - PS2Keyboard library
  Copyright (c) 2007 Free Software Foundation.  All right reserved.
  Written by Christian Weichel <info@32leaves.net>

  ** Mostly rewritten Paul Stoffregen <paul@pjrc.com> 2010, 2011
  ** Modified for use beginning with Arduino 13 by L. Abraham Smith, <n3bah@microcompdesign.com> * 
  ** Modified for easy interrup pin assignement on method begin(datapin,irq_pin). Cuningan <cuninganreset@gmail.com> **

  for more information you can read the original wiki in arduino.cc
  at http://www.arduino.cc/playground/Main/PS2Keyboard
  or http://www.pjrc.com/teensy/td_libs_PS2Keyboard.html

  Version 2.4 (March 2013)
  - Support Teensy 3.0, Arduino Due, Arduino Leonardo & other boards
  - French keyboard layout, David Chochoi, tchoyyfr at yahoo dot fr

  Version 2.3 (October 2011)
  - Minor bugs fixed

  Version 2.2 (August 2011)
  - Support non-US keyboards - thanks to Rainer Bruch for a German keyboard :)

  Version 2.1 (May 2011)
  - timeout to recover from misaligned input
  - compatibility with Arduino "new-extension" branch
  - TODO: send function, proposed by Scott Penrose, scooterda at me dot com

  Version 2.0 (June 2010)
  - Buffering added, many scan codes can be captured without data loss
    if your sketch is busy doing other work
  - Shift keys supported, completely rewritten scan code to ascii
  - Slow linear search replaced with fast indexed table lookups
  - Support for Teensy, Arduino Mega, and Sanguino added

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
  You should have received a copy of the GNU Lesser General Public
  License along with this library; if not, write to the Free Software
  Foundation, Inc., 51 Franklin St, Fifth Floor, Boston, MA  02110-1301  USA
*/

#include "PS2Keyboard.h"

#define BUFFER_SIZE 45
static volatile uint8_t buffer[BUFFER_SIZE];
static volatile uint8_t head, tail;
static uint8_t DataPin;
static uint8_t CharBuffer=0;
static uint8_t UTF8next=0;
static const PS2Keymap_t *keymap=NULL;

// The ISR for the external interrupt
void ps2interrupt(void)
{
	static uint8_t bitcount=0;
	static uint8_t incoming=0;
	static uint32_t prev_ms=0;
	uint32_t now_ms;
	uint8_t n, val;

	val = digitalRead(DataPin);
	now_ms = millis();
	if (now_ms - prev_ms > 250) {
		bitcount = 0;
		incoming = 0;
	}
	prev_ms = now_ms;
	n = bitcount - 1;
	if (n <= 7) {
		incoming |= (val << n);
	}
	bitcount++;
	if (bitcount == 11) {
		uint8_t i = head + 1;
		if (i >= BUFFER_SIZE) i = 0;
		if (i != tail) {
			buffer[i] = incoming;
			head = i;
		}
		bitcount = 0;
		incoming = 0;
	}
}

static inline uint8_t get_scan_code(void)
{
	uint8_t c, i;

	i = tail;
	if (i == head) return 0;
	i++;
	if (i >= BUFFER_SIZE) i = 0;
	c = buffer[i];
	tail = i;
	return c;
}

// http://www.quadibloc.com/comp/scan.htm
// http://www.computer-engineering.org/ps2keyboard/scancodes2.html

// These arrays provide a simple key map, to turn scan codes into ISO8859
// output.  If a non-US keyboard is used, these may need to be modified
// for the desired output.
//

const PROGMEM PS2Keymap_t PS2Keymap_US = {
  // without shift
	{0, PS2_F9, 0, PS2_F5, PS2_F3, PS2_F1, PS2_F2, PS2_F12,
	0, PS2_F10, PS2_F8, PS2_F6, PS2_F4, PS2_TAB, '`', 0,
	0, 0 /*Lalt*/, 0 /*Lshift*/, 0, 0 /*Lctrl*/, 'q', '1', 0,
	0, 0, 'z', 's', 'a', 'w', '2', 0,
	0, 'c', 'x', 'd', 'e', '4', '3', 0,
	0, ' ', 'v', 'f', 't', 'r', '5', 0,
	0, 'n', 'b', 'h', 'g', 'y', '6', 0,
	0, 0, 'm', 'j', 'u', '7', '8', 0,
	0, ',', 'k', 'i', 'o', '0', '9', 0,
	0, '.', '/', 'l', ';', 'p', '-', 0,
	0, 0, '\'', 0, '[', '=', 0, 0,
	0 /*CapsLock*/, 0 /*Rshift*/, PS2_ENTER /*Enter*/, ']', 0, '\\', 0, 0,
	0, 0, 0, 0, 0, 0, PS2_BACKSPACE, 0,
	0, '1', 0, '4', '7', 0, 0, 0,
	'0', '.', '2', '5', '6', '8', PS2_ESC, 0 /*NumLock*/,
	PS2_F11, '+', '3', '-', '*', '9', PS2_SCROLL, 0,
	0, 0, 0, PS2_F7 },
  // with shift
	{0, PS2_F9, 0, PS2_F5, PS2_F3, PS2_F1, PS2_F2, PS2_F12,
	0, PS2_F10, PS2_F8, PS2_F6, PS2_F4, PS2_TAB, '~', 0,
	0, 0 /*Lalt*/, 0 /*Lshift*/, 0, 0 /*Lctrl*/, 'Q', '!', 0,
	0, 0, 'Z', 'S', 'A', 'W', '@', 0,
	0, 'C', 'X', 'D', 'E', '$', '#', 0,
	0, ' ', 'V', 'F', 'T', 'R', '%', 0,
	0, 'N', 'B', 'H', 'G', 'Y', '^', 0,
	0, 0, 'M', 'J', 'U', '&', '*', 0,
	0, '<', 'K', 'I', 'O', ')', '(', 0,
	0, '>', '?', 'L', ':', 'P', '_', 0,
	0, 0, '"', 0, '{', '+', 0, 0,
	0 /*CapsLock*/, 0 /*Rshift*/, PS2_ENTER /*Enter*/, '}', 0, '|', 0, 0,
	0, 0, 0, 0, 0, 0, PS2_BACKSPACE, 0,
	0, '1', 0, '4', '7', 0, 0, 0,
	'0', '.', '2', '5', '6', '8', PS2_ESC, 0 /*NumLock*/,
	PS2_F11, '+', '3', '-', '*', '9', PS2_SCROLL, 0,
	0, 0, 0, PS2_F7 },
	0
};
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

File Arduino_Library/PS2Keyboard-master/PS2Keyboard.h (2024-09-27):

/*
  PS2Keyboard.h - PS2Keyboard library
  Copyright (c) 2007 Free Software Foundation.  All right reserved.
  Written by Christian Weichel <info@32leaves.net>

  ** Mostly rewritten Paul Stoffregen <paul@pjrc.com>, June 2010
  ** Modified for use with Arduino 13 by L. Abraham Smith, <n3bah@microcompdesign.com> * 
  ** Modified for easy interrup pin assignement on method begin(datapin,irq_pin). Cuningan <cuninganreset@gmail.com> **

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
  You should have received a copy of the GNU Lesser General Public
  License along with this library; if not, write to the Free Software
  Foundation, Inc., 51 Franklin St, Fifth Floor, Boston, MA  02110-1301  USA
*/


#ifndef PS2Keyboard_h
#define PS2Keyboard_h

#if defined(ARDUINO) && ARDUINO >= 100
#include "Arduino.h" // for attachInterrupt, FALLING
#else
#include "WProgram.h"
#endif

#include "utility/int_pins.h"

// Every call to read() returns a single byte for each
// keystroke.  These configure what byte will be returned
// for each "special" key.  To ignore a key, use zero.
#define PS2_TAB						9
#define PS2_ENTER					13
#define PS2_BACKSPACE			8
#define PS2_ESC						27
#define PS2_INSERT				0
#define PS2_DELETE				127
#define PS2_HOME					0
#define PS2_END						0
#define PS2_PAGEUP				25
#define PS2_PAGEDOWN			26
#define PS2_UPARROW				20
#define PS2_LEFTARROW			17
#define PS2_DOWNARROW			19
#define PS2_RIGHTARROW		18
#define PS2_F1				0
#define PS2_F2				0
#define PS2_F3				0
#define PS2_F4				0
#define PS2_F5				0
#define PS2_F6				0
#define PS2_F7				0
#define PS2_F8				0
#define PS2_F9				0
#define PS2_F10				0
#define PS2_F11				0
#define PS2_F12				0
#define PS2_SCROLL			0
#define PS2_EURO_SIGN			0

#define PS2_INVERTED_EXCLAMATION	161 // ¡
#define PS2_CENT_SIGN			162 // ¢
#define PS2_POUND_SIGN			163 // £
#define PS2_CURRENCY_SIGN		164 // ¤
#define PS2_YEN_SIGN			165 // ¥
#define PS2_BROKEN_BAR                 	166 // ¦
#define PS2_SECTION_SIGN		167 // §
#define PS2_DIAERESIS			168 // ¨
#define PS2_COPYRIGHT_SIGN		169 // ©
#define PS2_FEMININE_ORDINAL		170 // ª
#define PS2_LEFT_DOUBLE_ANGLE_QUOTE	171 // «
#define PS2_NOT_SIGN			172 // ¬
#define PS2_HYPHEN			173
#define PS2_REGISTERED_SIGN		174 // ®
#define PS2_MACRON			175 // ¯
#define PS2_DEGREE_SIGN			176 // °
#define PS2_PLUS_MINUS_SIGN		177 // ±
#define PS2_SUPERSCRIPT_TWO		178 // ²
#define PS2_SUPERSCRIPT_THREE		179 // ³
#define PS2_ACUTE_ACCENT		180 // ´
#define PS2_MICRO_SIGN			181 // µ
#define PS2_PILCROW_SIGN		182 // ¶
#define PS2_MIDDLE_DOT			183 // ·
#define PS2_CEDILLA			184 // ¸
#define PS2_SUPERSCRIPT_ONE		185 // ¹
#define PS2_MASCULINE_ORDINAL		186 // º
#define PS2_RIGHT_DOUBLE_ANGLE_QUOTE	187 // »
#define PS2_FRACTION_ONE_QUARTER	188 // ¼
#define PS2_FRACTION_ONE_HALF		189 // ½
#define PS2_FRACTION_THREE_QUARTERS	190 // ¾
#define PS2_INVERTED_QUESTION_MARK	191 // ¿
#define PS2_A_GRAVE			192 // À
#define PS2_A_ACUTE			193 // Á
#define PS2_A_CIRCUMFLEX		194 // Â
#define PS2_A_TILDE			195 // Ã
#define PS2_A_DIAERESIS			196 // Ä
#define PS2_A_RING_ABOVE		197 // Å
#define PS2_AE				198 // Æ
#define PS2_C_CEDILLA			199 // Ç
#define PS2_E_GRAVE			200 // È
#define PS2_E_ACUTE			201 // É
#define PS2_E_CIRCUMFLEX		202 // Ê
#define PS2_E_DIAERESIS			203 // Ë
#define PS2_I_GRAVE			204 // Ì
#define PS2_I_ACUTE			205 // Í
#define PS2_I_CIRCUMFLEX		206 // Î
#define PS2_I_DIAERESIS			207 // Ï
#define PS2_ETH				208 // Ð
#define PS2_N_TILDE			209 // Ñ
#define PS2_O_GRAVE			210 // Ò
#define PS2_O_ACUTE			211 // Ó
#define PS2_O_CIRCUMFLEX		212 // Ô
#define PS2_O_TILDE			213 // Õ
#define PS2_O_DIAERESIS			214 // Ö
#define PS2_MULTIPLICATION		215 // ×
#define PS2_O_STROKE			216 // Ø
#define PS2_U_GRAVE			217 // Ù
#define PS2_U_ACUTE			218 // Ú
#define PS2_U_CIRCUMFLEX		219 // Û
#define PS2_U_DIAERESIS			220 // Ü
#define PS2_Y_ACUTE			221 // Ý
#define PS2_THORN			222 // Þ
#define PS2_SHARP_S			223 // ß
#define PS2_a_GRAVE			224 // à
#define PS2_a_ACUTE			225 // á
#define PS2_a_CIRCUMFLEX		226 // â
#define PS2_a_TILDE			227 // ã
#define PS2_a_DIAERESIS			228 // ä
#define PS2_a_RING_ABOVE		229 // å
#define PS2_ae				230 // æ
#define PS2_c_CEDILLA			231 // ç
#define PS2_e_GRAVE			232 // è
#define PS2_e_ACUTE			233 // é
#define PS2_e_CIRCUMFLEX		234 // ê
#define PS2_e_DIAERESIS			235 // ë
#define PS2_i_GRAVE			236 // ì
#define PS2_i_ACUTE			237 // í
#define PS2_i_CIRCUMFLEX		238 // î
#define PS2_i_DIAERESIS			239 // ï
#define PS2_eth				240 // ð
#define PS2_n_TILDE			241 // ñ
#define PS2_o_GRAVE			242 // ò
#define PS2_o_ACUTE			243 // ó
#define PS2_o_CIRCUMFLEX		244 // ô
#define PS2_o_TILDE			245 // õ
#define PS2_o_DIAERESIS			246 // ö
#define PS2_DIVISION			247 // ÷
#define PS2_o_STROKE			248 // ø
#define PS2_u_GRAVE			249 // ù
#define PS2_u_ACUTE			250 // ú
#define PS2_u_CIRCUMFLEX		251 // û
#define PS2_u_DIAERESIS			252 // ü
#define PS2_y_ACUTE			253 // ý
#define PS2_thorn			254 // þ
#define PS2_y_DIAERESIS			255 // ÿ


#define PS2_KEYMAP_SIZE 136
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

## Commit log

2024-10-21 Update esp32_MAX7219_64x16.ino
    只有上班時間才點亮
2024-11-07 Update esp32_MAX7219_64x16.ino
    修正判斷上班時間的bug
2026-01-21 更新照片與私印
    [KiCad_Esp32_LotNoDisplay-B_Cu.gbr, KiCad_Esp32_LotNoDisplay-B_Mask.gbr, KiCad_Esp32_LotNoDisplay-B_Paste.gbr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]

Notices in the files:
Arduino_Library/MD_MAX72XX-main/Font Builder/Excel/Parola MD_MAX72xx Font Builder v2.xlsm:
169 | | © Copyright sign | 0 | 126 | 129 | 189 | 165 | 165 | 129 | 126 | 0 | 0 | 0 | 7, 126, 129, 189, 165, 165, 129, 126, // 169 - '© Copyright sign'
